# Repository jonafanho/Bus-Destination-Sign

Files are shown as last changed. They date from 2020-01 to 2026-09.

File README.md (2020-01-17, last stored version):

# Bus Destination Sign
A simulation of LED or flip dot bus destination signs using the STM32 Blue Pill.

## Quick Start
### First Run
1. Insert an empty micro SD card (formatted to FAT32) into the SD card slot.
1. Power up the STM32 microcontroller using a Micro USB cable.
1. After the system finishes loading, the screen will turn black. The necessary folders and configuration files will be automatically set up on the SD card.
1. Turn off the microcontroller by unplugging the Micro USB cable, then remove the SD card from the SD card slot.

### Adding Images
1. On a computer, download or obtain images to be shown on the destination signs. Some good sites include [HKBRDA](https://www.hkbrda.org/rddc/main.php) and [Stopreporter](https://sites.google.com/site/stopreporter2003/edisplay).
1. Convert all images into the BMP file format. [Online converter](https://image.online-convert.com/convert-to-bmp) is an easy site to convert images quickly.
1. Open the SD card on the computer. Inside the SD card, you should see the following folders:
   * In the root directory, there should be ten folders named `0` to `9`. These folders group images of the same bus routes together.
   * In each of the ten folders, there should be three folders named `front`, `side`, and `back`. These folders designate which images appear on the front, side, and rear displays.
   * If these folders don't exist, follow the [First Run](#first-run) steps above to automatically create the necessary folders and configuration files.
1. Copy the BMP files to any of the `front`, `side`, or `back` folders on the SD card.
   * Images of the same bus route should be grouped together.
   * Images of the front, side, and back displays should go into their respective folders.
   * An example of the SD card file structure is shown [below](#example-sd-card-file-structure).
1. Safely eject the SD card from the computer and reinsert the SD card to the SD card slot.
1. Power up the STM32 microcontroller again.
   * The images from `0/front`, `0/side`, and `0/back` should show up on the front, side, and back displays respectively.
   * On the device or a connected remote, press the button to change routes. The images from `1/front`, `1/side`, and `1/back` should now show up.
   * Pressing the button again should cycle thorugh the routes. Note that if all three `front`, `side`, and `back` folders of a group is empty, the group will be skipped.

### Example SD Card File Structure
```
root
├───global_settings.txt
├───0
│   ├───image_settings.txt
│   ├───front
│   │   ├───KMB-74X-00.bmp
│   │   └───KMB-74X-01.bmp
│   ├───side
│   │   └───KMB-74X-10.bmp
│   └───back
│       └───KMB-74X-20.bmp
├───1
│   ├───image_settings.txt
│   ├───front
│   │   ├───KMB-680-00.bmp
│   │   ├───KMB-680-01.bmp
│   │   └───KMB-680-02.bmp
│   ├───side
│   │   ├───KMB-680-10.bmp
│   │   └───KMB-680-11.bmp
│   └───back
│       ├───KMB-680-20.bmp
│       └───KMB-680-21.bmp
...
└───9
    ├───image_settings.txt
    ├───front
    │   └───KMB-special-00.bmp
    ├───side
    └───back
```

## Configuration
There are two types of settings that can be configured by the user. All fields accept positive integers. If a corrupted settings file is detected, it will be reset to its default values.

### Global Settings
These settings control the display animation as a whole. The configuration file, `global_settings.txt`, is in the root of the SD card.

The contents of `global_settings.txt` with its default values are shown below.
```
scroll_animation=1
switch_delay=2
```
Parameter | Description
--- | ---
`scroll_animation` | Defines whether a scrolling animation will be used when switching between images. The scrolling animation simulates flip dot displays.<br>`scroll_animation=0`: No scrolling animation<br>`scroll_animation=1`: Scrolling animation
`switch_delay` | The amount of time (in seconds) to show each image before switching to the next one.<br>Note: The actual time might be greater than the number specified here depending on the time it takes to load the next image.

### Image Settings
These settings control the way images are scaled or cropped. The configuration file, `image_settings.txt`, is inside each of the ten folders `0` to `9` on the SD card.

"Scale" refers to how many pixels (in one axis) on the BMP image maps to one pixel (in one axis) on the physical display. For example, a scale of 3 means that every 3x3 square on the BMP image corresponds to one pixel on the physical display.

"Crop" refers to how many pixels (symmetrical on all sides) of the BMP image will not be shown on the physical display.

The contents of `image_settings.txt` with its default values are shown below.
```
front_scale=3
front_crop=20
side_scale=3
side_crop=19
back_scale=1
back_crop=0
```
Parameter | Description
--- | ---
`front_scale` | The scaling of the images on the front display.
`front_crop` | The crop of the images on the front display.
`side_scale` | The scaling of the images on the side display.
`side_crop` | The crop of the images on the side display.
`back_scale` | The scaling of the images on the back display.
`back_crop` | The crop of the images on the back display.

## Special Scrolling
To use special scrolling on an image, the file name must begin with an exclamation mark (`!`).

After the exclamation mark, the file name should contain a three digit number. This number corresponds to the number of pixels from the left edge (after scaling) where the image should be split. The pixels before the split to the left will display as a stationary image, and the pixels on or after the split to the right will be scrolled. If the number is less than three digits long, it should be padded by zeros.

An example of file names implementing special scrolling is shown below.
```
!046-NWFB-682.bmp
!112-NWFB-15.bmp
```

## Troubleshooting
* My images are not showing up!
  * Make sure the images are in BMP format. (8, 16, 24, and 32-bit uncompressed BMP files are supported.)
  * Make sure the BMP files are in any of the three folders (front, side, or back). They shouldn't be anywhere else or nested inside those folders.
  * Make sure the image crop value is low enough that at least a part of the image is still visible.
* My images take forever to load!
  * Keep the image sizes small, preferably smaller than 500x500 pixels.
  * Images will load slower for the first time as the cache is being created.
* My SD card failed to initalize!
  * Make sure the SD card is formatted to FAT32.
  * Make sure the SD card is clean, inserted fully into the SD card slot, and oriented in the correct direction.

## Building it Yourself
Refer to the [Installation](https://github.com/jonafanho/Bus-Destination-Sign/blob/master/Installation.md) page for instructions.

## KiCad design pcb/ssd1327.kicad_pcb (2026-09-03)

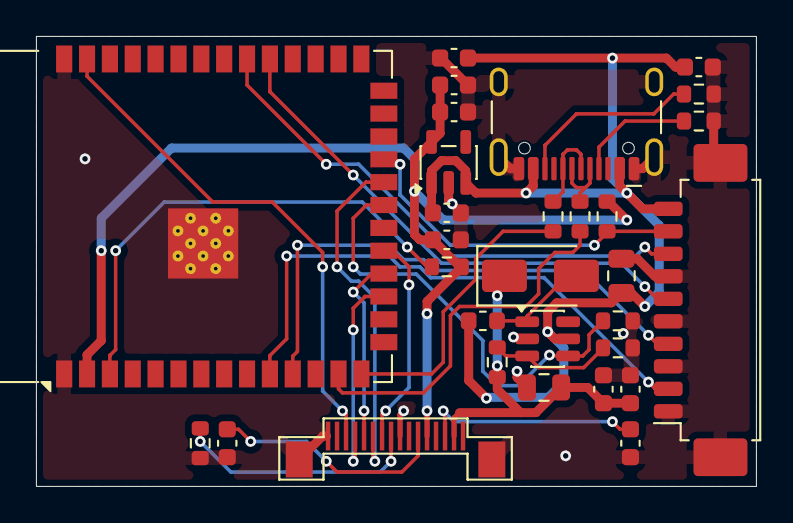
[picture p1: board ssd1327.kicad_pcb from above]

Board: 2 copper layers, 40.0 x 25.0 mm, 30 parts (0 on the bottom side), 27 nets.

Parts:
C1, C5: 1uF; C_0603_1608Metric
C2: 4.7uF; C_0603_1608Metric
C3, C7, C11: 10uF; C_0603_1608Metric
C4, C8, C12: 0.1uF; C_0603_1608Metric
C6: 2.2uF; C_0603_1608Metric
C9, C10: 22uF; C_0805_2012Metric
D1: SS34; D_SMA
J1: Display Connector Input; Molex_PicoBlade_53261-1071_1x10-1MP_P1.25mm_Horizontal
J2: SSD1327 16-Pin Connector; 16-pin
J3: USB_C_Receptacle_USB2.0_16P; USB_C_Receptacle_HCTL_HC-TYPE-C-16P-01A
L1: 10uH; L_0603_1608Metric
R1, R7, R10: 10k; R_0603_1608Metric
R2: 1M; R_0603_1608Metric
R3, R4: 5.1k; R_0603_1608Metric
R5, R6: 22R; R_0603_1608Metric
R8: 100k; R_0603_1608Metric
R9: 200k; R_0603_1608Metric
U1: AP2112K-3.3; SOT-23-5
U2: ESP32-S3-WROOM-1
U3: MT3608; SOT-23-6

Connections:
+5V: C3.1, C4.1, C5.1, C9.1, J1.10 (5V), J3.A4 (VBUS), J3.A9 (VBUS), J3.B4 (VBUS), J3.B9 (VBUS), L1.1, U1.1 (VIN), U1.3 (EN), U3.5 (IN)
/ESP32 for SSD1327/3V3: C6.1, C7.1, C8.1, J2.5 (VCI), R1.1, R7.1, U1.5 (VOUT), U2.2 (3V3)
/ESP32 for SSD1327/CLK: J1.2 (CLK), U2.10 (IO17)
/ESP32 for SSD1327/GPIO1: J2.14 (MOSI), U2.39 (IO1)
/ESP32 for SSD1327/GPIO9: J2.13 (CLK), U2.17 (IO9)
/ESP32 for SSD1327/GPIO10: J2.12 (DC), U2.18 (IO10)
/ESP32 for SSD1327/GPIO11: J2.10 (CS), U2.19 (IO11)
/ESP32 for SSD1327/GPIO13: R8.1, U2.21 (IO13), U3.4 (EN)
/ESP32 for SSD1327/GPIO14: J2.11 (RES), U2.22 (IO14)
/ESP32 for SSD1327/GPIO21: J1.9 (WAKE), R1.2, U2.23 (IO21)
/ESP32 for SSD1327/GPIO39: J1.8 (CS), U2.32 (IO39)
/ESP32 for SSD1327/MISO: J1.6 (MISO), U2.31 (IO38)
/ESP32 for SSD1327/MOSI: J1.4 (MOSI), U2.11 (IO18)
/MT3608 for SSD1327/12V: C10.1, C11.1, C12.1, D1.1 (K), J2.2 (VCC), R9.1
GND: C1.2, C2.2, C3.2, C4.2, C5.2, C6.2, C7.2, C8.2, C9.2, C10.2, C11.2, C12.2, J1.1 (GND), J1.3 (GND), J1.5 (GND), J1.7 (GND), J1.MP (GND), J2.0 (GND), J2.8 (VSS), J2.16 (VSS), J3.A1 (GND), J3.A12 (GND), J3.B1 (GND), J3.B12 (GND), J3.SH (SHIELD), R2.1, R3.2, R4.2, R8.2, R10.2, U1.2 (GND), U2.1 (GND), U2.40 (GND), U2.41 (GND), U3.2 (GND)
unnamed: D1.2 (A), L1.2, U3.1 (SW)
unnamed: J2.9 (IREF), R2.2
unnamed: C2.1, J2.3 (VCOMH)
unnamed: C1.1, J2.6 (VDD)
unnamed: J3.A5 (CC1), R4.1
unnamed: J3.B5 (CC2), R3.1
unnamed: J3.A6 (D+), J3.B6 (D+), R6.1
unnamed: J3.A7 (D-), J3.B7 (D-), R5.1
unnamed: R7.2, U2.3 (EN)
unnamed: R6.2, U2.14 (USB_D+)
unnamed: R5.2, U2.13 (USB_D-)
unnamed: R9.2, R10.1, U3.3 (FB)

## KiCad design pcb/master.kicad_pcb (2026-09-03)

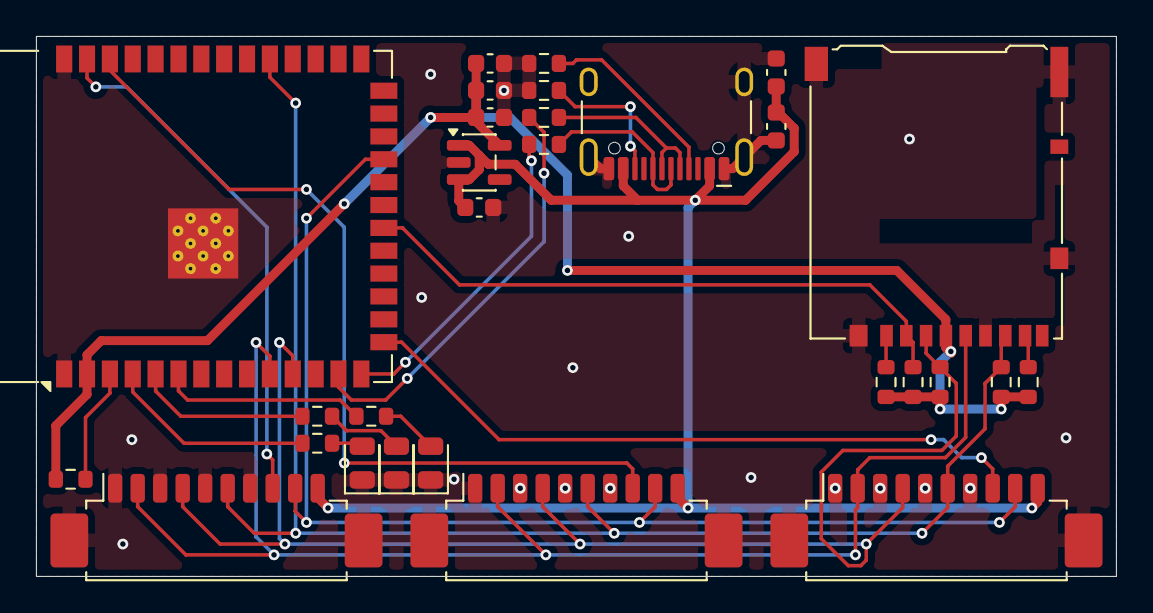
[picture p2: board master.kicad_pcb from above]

Board: 2 copper layers, 60.0 x 30.0 mm, 29 parts (0 on the bottom side), 26 nets.

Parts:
C1, C5: 10uF; C_0603_1608Metric
C2, C6: 0.1uF; C_0603_1608Metric
C3: 1uF; C_0603_1608Metric
C4: 2.2uF; C_0603_1608Metric
D1: Green LED; LED_0805_2012Metric
D2: Yellow LED; LED_0805_2012Metric
D3: Red LED; LED_0805_2012Metric
J1: Micro_SD_Card_Det2; microSD_HC_Hirose_DM3AT-SF-PEJM5
J2, J3, J4: Display Connector Output; Molex_PicoBlade_53261-1071_1x10-1MP_P1.25mm_Horizontal
J5: USB_C_Receptacle_USB2.0_16P; USB_C_Receptacle_HCTL_HC-TYPE-C-16P-01A
R1, R2, R4, R5, R6, R13: 10k; R_0603_1608Metric
R3, R7, R8: 470R; R_0603_1608Metric
R9, R10: 5.1k; R_0603_1608Metric
R11, R12: 22R; R_0603_1608Metric
U1: AP2112K-3.3; SOT-23-5
U2: ESP32-S3-WROOM-1

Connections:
+5V: C1.1, C2.1, C3.1, J2.10 (5V), J3.10 (5V), J4.10 (5V), J5.A4 (VBUS), J5.A9 (VBUS), J5.B4 (VBUS), J5.B9 (VBUS), U1.1 (VIN), U1.3 (EN)
/CLK: J1.5 (CLK), J2.2 (CLK), J3.2 (CLK), J4.2 (CLK), U2.10 (IO17)
/CS_DISPLAY_1: J2.8 (CS), U2.39 (IO1)
/CS_DISPLAY_2: J3.8 (CS), U2.38 (IO2)
/CS_DISPLAY_3: J4.8 (CS), U2.15 (IO3)
/MISO: J1.7 (DAT0), J2.6 (MISO), J3.6 (MISO), J4.6 (MISO), R2.2, U2.31 (IO38)
/MOSI: J1.3 (CMD), J2.4 (MOSI), J3.4 (MOSI), J4.4 (MOSI), R4.2, U2.11 (IO18)
/Master ESP32/3V3: C4.1, C5.1, C6.1, J1.4 (VDD), R1.1, R2.1, R4.1, R5.1, R6.1, R13.1, U1.5 (VOUT), U2.2 (3V3)
/Master ESP32/GPIO4: R8.2, U2.4 (IO4)
/Master ESP32/GPIO5: R7.2, U2.5 (IO5)
/Master ESP32/GPIO6: R3.2, U2.6 (IO6)
/Master ESP32/GPIO12: J1.2 (DAT3/CD), R5.2, U2.20 (IO12)
/WAKE: J2.9 (WAKE), J3.9 (WAKE), J4.9 (WAKE), U2.23 (IO21)
GND: C1.2, C2.2, C3.2, C4.2, C5.2, C6.2, D1.1 (K), D2.1 (K), D3.1 (K), J1.6 (VSS), J2.1 (GND), J2.3 (GND), J2.5 (GND), J2.7 (GND), J2.MP (GND), J3.1 (GND), J3.3 (GND), J3.5 (GND), J3.7 (GND), J3.MP (GND), J4.1 (GND), J4.3 (GND), J4.5 (GND), J4.7 (GND), J4.MP (GND), J5.A1 (GND), J5.A12 (GND), J5.B1 (GND), J5.B12 (GND), R9.2, R10.2, U1.2 (GND), U2.1 (GND), U2.40 (GND), U2.41 (GND)
unnamed: D1.2 (A), R3.1
unnamed: D2.2 (A), R7.1
unnamed: D3.2 (A), R8.1
unnamed: J1.8 (DAT1), R1.2
unnamed: J1.1 (DAT2), R6.2
unnamed: J5.A5 (CC1), R10.1
unnamed: J5.B5 (CC2), R9.1
unnamed: J5.A6 (D+), J5.B6 (D+), R12.1
unnamed: J5.A7 (D-), J5.B7 (D-), R11.1
unnamed: R13.2, U2.3 (EN)
unnamed: R12.2, U2.14 (USB_D+)
unnamed: R11.2, U2.13 (USB_D-)

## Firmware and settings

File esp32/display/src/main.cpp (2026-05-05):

#include <Arduino.h>
#include <init_print.h>
#include <spi_slave.h>
#include <ssd1327.h>
#include <ssd1322.h>
#include <display_transaction_slave.h>
#include <stream_reader.h>

#define DISPLAY_DRIVER SSD1322
#define DISPLAY_ROTATED false
#define DISPLAY_HAS_WIPE true
#define DISPLAY_PIXELATED_TYPE 0

InitPrint initPrint("Display");
SPISlave spiSlave;
DISPLAY_DRIVER displayDriver(DISPLAY_ROTATED, DISPLAY_HAS_WIPE, DISPLAY_PIXELATED_TYPE);
DisplayTransactionSlave displayTransactionSlave;
StreamReader streamReader;

void spiTask(void *pvParameters)
{
	while (true)
	{
		spiSlave.tick();
		delay(1);
	}
}

void setup()
{
	Serial.begin(115200);
	Serial.println("");

	initPrint.init(spiSlave.init(), "SPI device");
	initPrint.init(displayDriver.init(), "Display driver");

	xTaskCreatePinnedToCore(spiTask, "SPI", 4096, NULL, 2, NULL, 0);
}

void loop()
{
	displayTransactionSlave.tick(&spiSlave, &streamReader, &displayDriver);
}

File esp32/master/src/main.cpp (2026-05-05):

#include <Arduino.h>
#include <LittleFS.h>
#include <init_print.h>
#include <spi_master.h>
#include <display_transaction_master.h>
#include "server_handler.h"
#include "settings.h"

InitPrint initPrint("Main");
SPIMaster spiMaster1(GPIO_NUM_1);
SPIMaster spiMaster2(GPIO_NUM_2);
SPIMaster spiMaster3(GPIO_NUM_3);
DisplayTransactionMaster displayTransactionMaster1(0);
DisplayTransactionMaster displayTransactionMaster2(1);
DisplayTransactionMaster displayTransactionMaster3(2);
ServerHandler serverHandler;
Settings settings;

constexpr gpio_num_t PIN_LED_RED = GPIO_NUM_4;
constexpr gpio_num_t PIN_LED_YELLOW = GPIO_NUM_5;
constexpr gpio_num_t PIN_LED_GREEN = GPIO_NUM_6;

void setStatusLights(bool red, bool yellow, bool green)
{
	digitalWrite(PIN_LED_RED, red);
	digitalWrite(PIN_LED_YELLOW, yellow);
	digitalWrite(PIN_LED_GREEN, green);
}

void setup()
{
	Serial.begin(115200);
	Serial.println("");

	pinMode(PIN_LED_RED, OUTPUT);
	pinMode(PIN_LED_YELLOW, OUTPUT);
	pinMode(PIN_LED_GREEN, OUTPUT);

	setStatusLights(false, false, true);
	delay(500);
	setStatusLights(false, true, false);
	delay(500);
	setStatusLights(true, false, false);
	delay(500);

	initPrint.init(LittleFS.begin() || (LittleFS.format() && LittleFS.begin()), "LittleFS");
	initPrint.init(spiMaster1.init(), "SPI device 1");
	initPrint.init(spiMaster2.init(), "SPI device 2");
	initPrint.init(spiMaster3.init(), "SPI device 3");
	initPrint.init(SPIMaster::initBus(), "SPI bus and SD card");
	initPrint.init(displayTransactionMaster1.init(), "SD file structure 1");
	initPrint.init(displayTransactionMaster2.init(), "SD file structure 2");
	initPrint.init(displayTransactionMaster3.init(), "SD file structure 3");

	serverHandler.init(&settings);
	setStatusLights(false, false, false);
}

unsigned long nextDisplayMillis = 0;

void loop()
{
	serverHandler.tick(&settings);

	if (millis() >= nextDisplayMillis)
	{
		setStatusLights(false, false, true);
		displayTransactionMaster1.nextDisplay(&spiMaster1);
		displayTransactionMaster2.nextDisplay(&spiMaster2);
		displayTransactionMaster3.nextDisplay(&spiMaster3);
		nextDisplayMillis = millis() + 15000;
		setStatusLights(false, false, false);
	}
}

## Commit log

2020-07-28 Implemented a test button to send a POST request.
2020-07-28 Test button updates the corresponding screen.
2020-08-02 Test button for multiple images.
2020-08-08 Added group switching by web selection.
2020-08-10 Upload button uploads all groups at once.
2021-12-29 Added button control for the display
2025-10-08 Rewrite with Spring Boot, Angular, and PlatformIO
2025-10-22 Add Spring AOT
2025-12-17 Updated Angular and added upload button
2026-01-01 First draft of the ESP32 SSD1322 PCB design
    [ssd1322.kicad_pcb, ssd1322.kicad_sch]
2026-01-02 Copy and paste image settings buttons
2026-01-11 Updated SPI setup for SD card
2026-01-16 Initial code for the custom PCB with the ESP32
2026-01-18 Added ESP32 code with SPI library
2026-01-22 ESP32 master and display code
2026-01-23 Use esp_lcd library for the display driver
2026-01-26 Reroute SSD1322 PCB
    [bus_destination_sign.kicad_pcb, bus_destination_sign.kicad_sch, ssd1322.kicad_pcb]
2026-01-28 Added ESP32 master circuit
    [bus_destination_sign.kicad_pcb, bus_destination_sign.kicad_sch, esp32.kicad_sch]
2026-01-28 Updated LED footprints
    [bus_destination_sign.kicad_pcb, bus_destination_sign.kicad_sch]
2026-01-28 Fixed 3.3V connections and SD card orientation
    [bus_destination_sign.kicad_pcb, bus_destination_sign.kicad_sch, esp32.kicad_sch]
2026-01-28 Edited pin assignments in the code
2026-03-05 Added LED status lights in the code
2026-03-11 Added SSD1327 circuit
    [bus_destination_sign.kicad_sch, esp32.kicad_sch, mt7608.kicad_sch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]
2026-03-11 Fix MT3608 schematic naming
    [mt3608.kicad_sch]
2026-03-12 Split PCB into modules
    [bus_destination_sign.kicad_pcb, bus_destination_sign.kicad_sch, esp32.kicad_sch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]
2026-03-12 SSD1327 PCB routing
    [esp32.kicad_sch, mt3608.kicad_sch, ssd1322.kicad_pcb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]
2026-03-12 Master board PCB routing
    [esp32.kicad_sch, master.kicad_pcb, master.kicad_sch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]
2026-03-28 Rename project and added update workflow
    [esp32.kicad_sch, master.kicad_sch, mt3608.kicad_sch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]
2026-04-01 Testing file loading with existing displays
    [partitions.csv]
2026-04-16 Refactor the stream reader and SPI classes
2026-04-27 First draft of the SSD1327 driver
2026-04-30 Improved SPI payload size limit
    [partitions.csv]
2026-05-01 Pass CS pin for SPI master and better SD initialization
2026-05-02 Use SdFat and Arduino SPI libraries
    [partitions.csv]
2026-05-04 Use preprocessors to import the correct display driver
    [main.cpp]
2026-05-05 Various fixes; see description
    - Fixed SD Card zip file directories
    - Fixed preprocessors
    - Generic images now have a default duration
    - Save settings to cookies
    - Auto reboot when initialization fails
    [main.cpp]
2026-09-03 Update project version and references
    [esp32.kicad_sch, master.kicad_pcb, master.kicad_sch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]
